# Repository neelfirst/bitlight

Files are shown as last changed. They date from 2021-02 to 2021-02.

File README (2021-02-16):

h1. bitlight

bitlight is an ultra-portable digital tealight.
- battery life: ~100 min
- color: warm white
- connectivity: none
- usb-c rechargeable
- serviceable battery
- one pot control

future revisions.
- speed up battery charging with a prod-grade IC
- get a thumbwheel that clicks to turn on
- add or replace with inductive charging
- fix the USB-C connector, no trusty sparkfun

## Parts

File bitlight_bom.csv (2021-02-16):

Qty | Part | Digikey | Value | Device | Package | Description
2 | C1;C2 | 478-10766-1-ND | 10u | C-EUC0603 | C0603 | CAPACITOR, European symbol
2 | C3;C4 | 478-5319-1-ND | 1u | C-EUC0603 | C0603 | CAPACITOR, European symbol
2 | C5;C6 | 478-1244-1-ND | 0.1u | C-EUC0603 | C0603 | CAPACITOR, European symbol
1 | D1 |  | 3W-AL-PCB | 3W-AL-PCB | AL-PCB-20MM
1 | D2 | 350-4382-1-ND | GREEN | LED-GREEN0603 | LED-0603 | Green SMD LED
1 | J1 | 455-1719-ND |  | JST_2MM_MALE | JST-2-SMD | JST 2MM MALE RA CONNECTOR
1 | J2 | 2183-2586-ND |  | USB_C16PIN | USB-C-16P | USB Type C 16Pin Connector
1 | P1 | 3352T-1-505LF-ND | 3352T-1-105 | 3352T-1 | 3352T-1
2 | R1; R2 | P123770CT-ND | 5.1k | R-US_R0603 | R0603 | RESISTOR, American symbol
3 | R3; R7; R8 | P123733CT-ND | 1k | R-US_R0603 | R0603 | RESISTOR, American symbol
1 | R4 | P123776CT-ND | 680r | R-US_R0603 | R0603 | RESISTOR, American symbol
1 | R5 | P123734CT-ND | 10k | R-US_R0603 | R0603 | RESISTOR, American symbol
1 | R6 | P7.5MGCT-ND | 7.5M | R-US_R0603 | R0603 | RESISTOR, American symbol
1 | R9 | CSRN2512FKR500CT-ND | 0.5r | R-EU_R2512 | R2512 | RESISTOR, European symbol
1 | U1 | 296-44196-1-ND | BQ21040DBVT | BQ21040DBVT | SOT95P280X145-6N | Check prices
1 | U2 | NCP500SN33T1GOSCT-ND | NCP500SN33 | MIC5205YM5 | SOT95P280X145-5N | None Check prices
1 | U3 | 296-44482-1-ND | TLV521DCKT | TLV521DCKT | SOT65P210X110-5N | Check prices
1 | U4 | SI4126DY-T1-GE3CT-ND | SI4126DY-T1-GE3 | SI4126DY-T1-GE3 | SOIC127P600X175-8N | Single N-Channel 30 V 0.00275 Ohm
2 | Z1;Z2 | 36-5100-ND | Jumper

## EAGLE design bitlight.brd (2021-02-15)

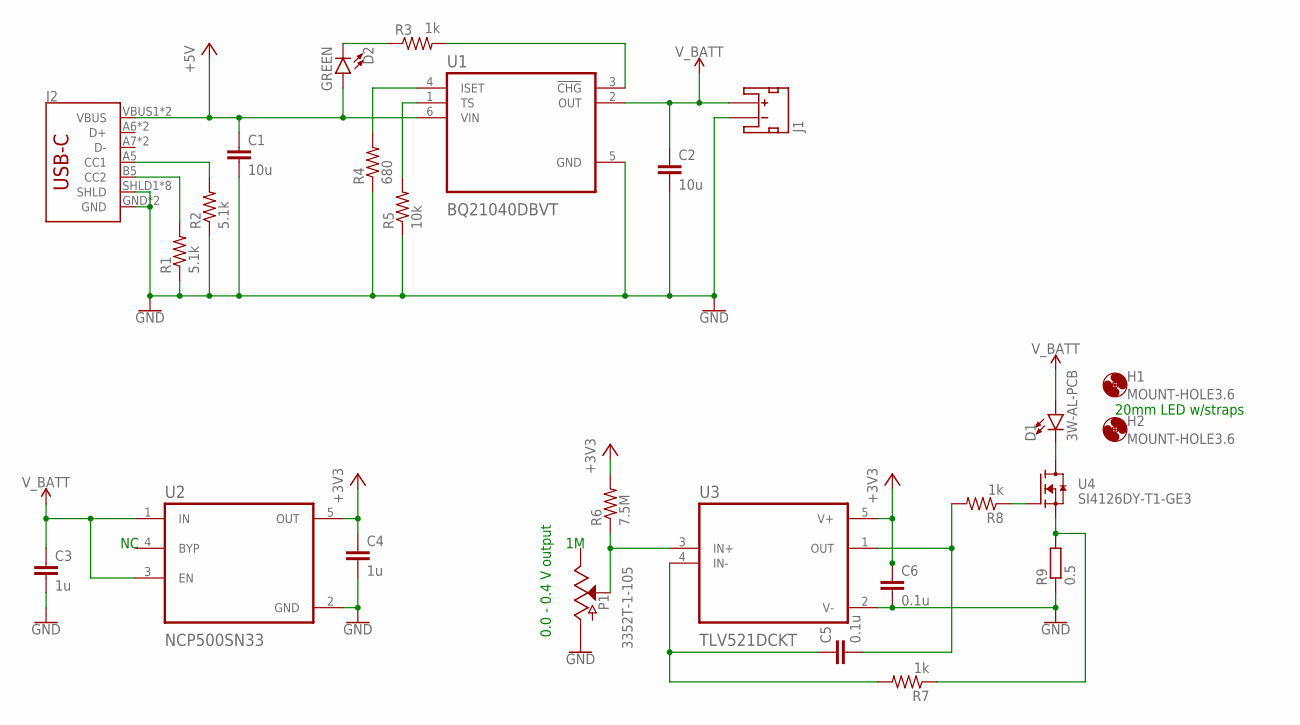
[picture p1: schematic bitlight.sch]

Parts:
C1, C2: 10u; C0603
C3, C4: 1u; C0603
C5, C6: 0.1u; C0603
D1: 3W-AL-PCB; AL-PCB-20MM
D2: GREEN; LED-0603
H1, H2: MOUNT-HOLE3.6; 3,6
J1: JST_2MM_MALE; JST-2-SMD
J2: USB_C16PIN; USB-C-16P
P1: 3352T-1-105; 3352T-1
R1, R2: 5.1k; R0603
R3, R7, R8: 1k; R0603
R4: 680; R0603
R5: 10k; R0603
R6: 7.5M; R0603
R9: 0.5; R2512
U1: BQ21040DBVT; SOT95P280X145-6N
U2: NCP500SN33; SOT95P280X145-5N
U3: TLV521DCKT; SOT65P210X110-5N
U4: SI4126DY-T1-GE3; SOIC127P600X175-8N

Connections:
+3V3: C4.1, C6.1, R6.2, U2.5 (OUT), U3.5 (V+)
+5V: C1.1, D2.A, J2.VBUS1 (VBUS), J2.VBUS2 (VBUS), U1.6 (VIN)
GND: C1.2, C2.2, C3.2, C4.2, C6.2, J1.1 (-), J2.GND, J2.GND2 (GND), J2.SHLD1 (SHLD), J2.SHLD2 (SHLD), J2.SHLD3 (SHLD), J2.SHLD4 (SHLD), J2.SHLD5 (SHLD), J2.SHLD6 (SHLD), J2.SHLD7 (SHLD), J2.SHLD8 (SHLD), P1.CCW (A), R1.1, R2.1, R4.1, R5.1, R9.1, U1.5 (GND), U2.2 (GND), U3.2 (V-)
unnamed: R3.2, U1.3 (!CHG)
unnamed: C5.1, R7.2, U3.4 (IN-)
unnamed: D1.- (C), U4.5 (D), U4.6 (D), U4.7 (D), U4.8 (D)
unnamed: D2.C, R3.1
unnamed: R7.1, R9.2, U4.1 (S), U4.2 (S), U4.3 (S)
unnamed: C5.2, R8.2, U3.1 (OUT)
unnamed: J2.B5 (CC2), R1.2
unnamed: R8.1, U4.4 (G)
unnamed: P1.WIPE (S), R6.1, U3.3 (IN+)
unnamed: J2.A5 (CC1), R2.2
PROG: R4.2, U1.4 (ISET)
THERM: R5.2, U1.1 (TS)
V_BATT: C2.1, C3.1, D1.+ (A), J1.2 (+), U1.2 (OUT), U2.1 (IN), U2.3 (EN)

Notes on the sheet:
0.0 - 0.4 V output
20mm LED w/straps

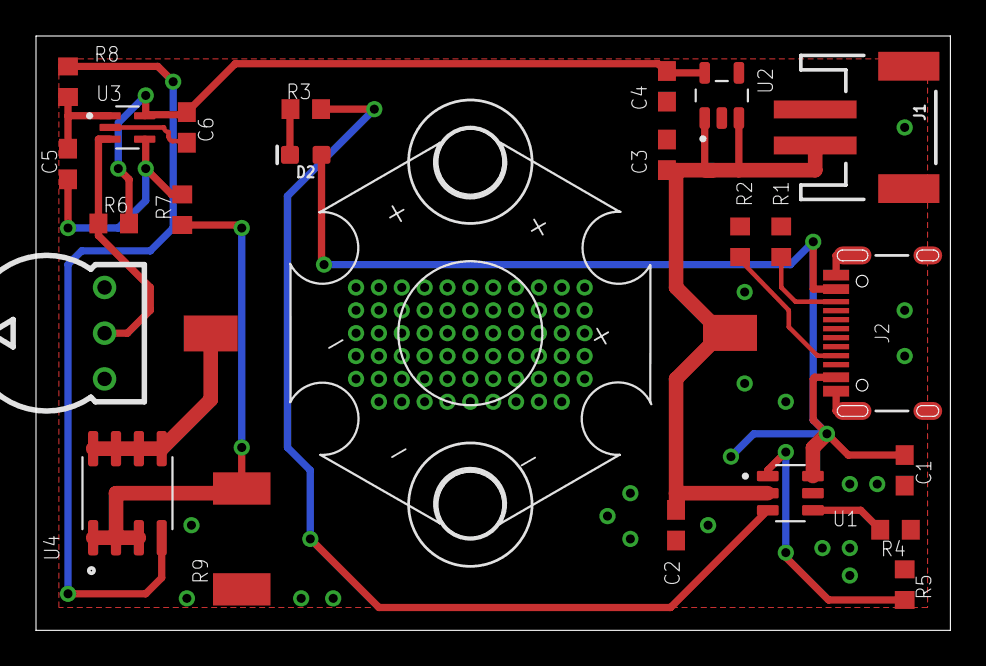
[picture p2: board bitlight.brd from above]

Board: 2 copper layers, 50.8 x 33.0 mm, 26 parts (0 on the bottom side), 16 nets.

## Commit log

2021-01-24 initial schematics
    [micro.sch, nano.sch]
2021-01-24 removing sch
    [micro.sch, nano.sch]
2021-02-14 added charger submodule, complete design
    [bitlight.brd, bitlight.sch]
2021-02-15 final design
    [bitlight.GBL, bitlight.GBO, bitlight.GBP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]
2021-02-16 bom update
    [bitlight_bom.csv]

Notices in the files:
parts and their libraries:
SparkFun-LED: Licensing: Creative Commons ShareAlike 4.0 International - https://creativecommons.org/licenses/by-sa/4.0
